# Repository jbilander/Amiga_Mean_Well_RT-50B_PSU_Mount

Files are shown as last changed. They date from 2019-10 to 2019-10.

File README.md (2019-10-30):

# Amiga Mean Well RT-50B PSU Mount
A 3d-printable PSU Mount for Mean Well RT-50B to fit inside an old Amiga PSU enclosure, two different versions

<a href="images/Amiga_Mean_Well_RT-50B_PSU.jpg">
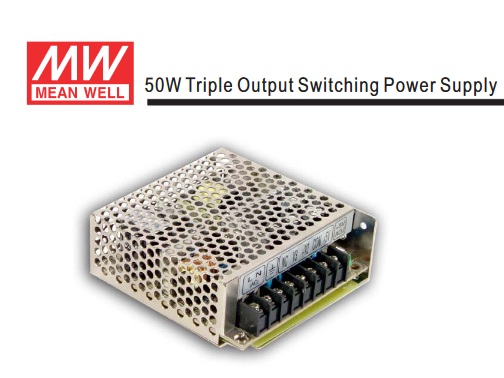
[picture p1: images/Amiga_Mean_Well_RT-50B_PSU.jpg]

</a>
<a href="images/V1/Amiga_Mean_Well_RT-50B_PSU_Mount_V1_pic1.jpg">
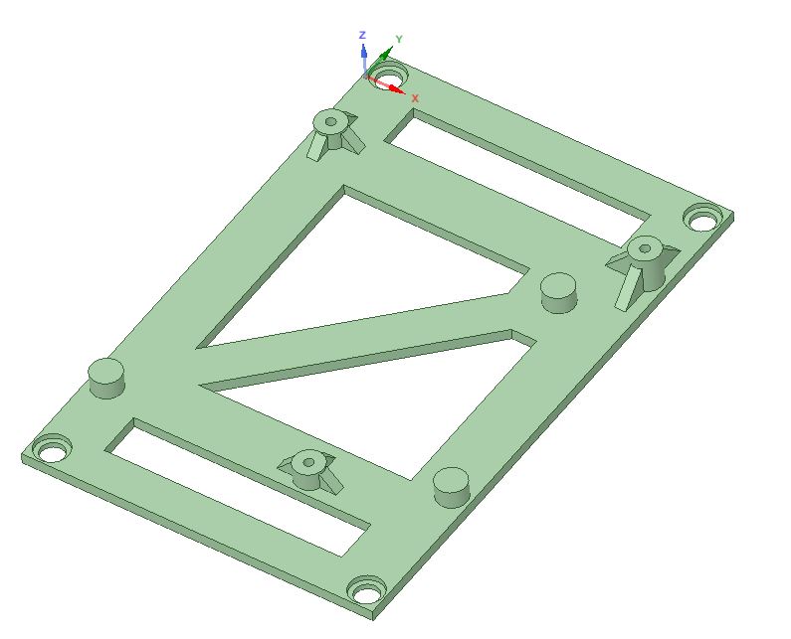
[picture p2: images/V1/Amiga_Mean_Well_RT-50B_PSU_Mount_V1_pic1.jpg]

</a>
<a href="images/V2/Amiga_Mean_Well_RT-50B_PSU_Mount_V2_pic1.jpg">
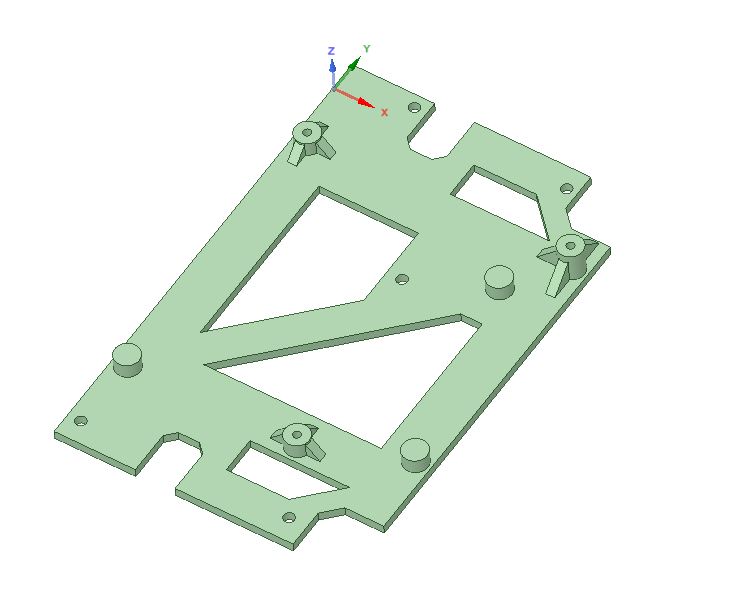
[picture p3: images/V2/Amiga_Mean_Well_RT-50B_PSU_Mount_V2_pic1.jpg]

</a>

The 3d-models was created in DesignSpark Mechanical 4.0

These two brackets fit different versions of the A500 PSU Enclosure

### Version 1

I did this 3d-print in ABS filament 250°/120° (Nozzle/Bed). It took ~4 hours. As you can see it is a snug fit in this old type of PSU case. I had to sand off a little of the ventilation fins on the sides in order for the Mean Well to fit in the case.

<a href="images/V1/Amiga_Mean_Well_RT-50B_PSU_Mount_V1_pic2.jpg">
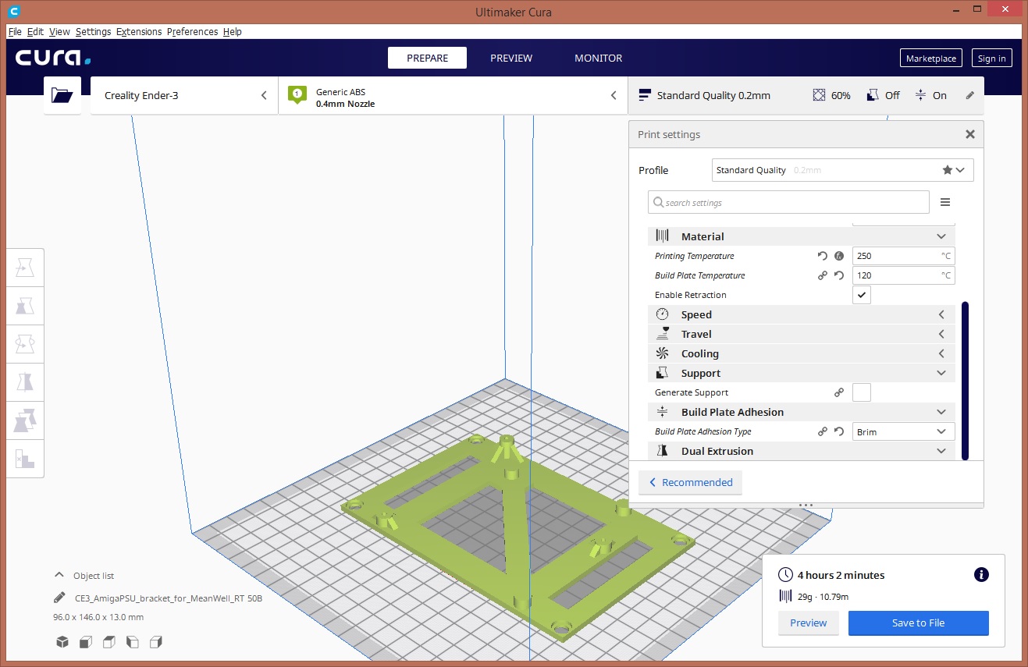
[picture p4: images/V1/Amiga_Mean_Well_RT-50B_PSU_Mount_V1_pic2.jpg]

</a>
<a href="images/V1/Amiga_Mean_Well_RT-50B_PSU_Mount_V1_pic3.jpg">
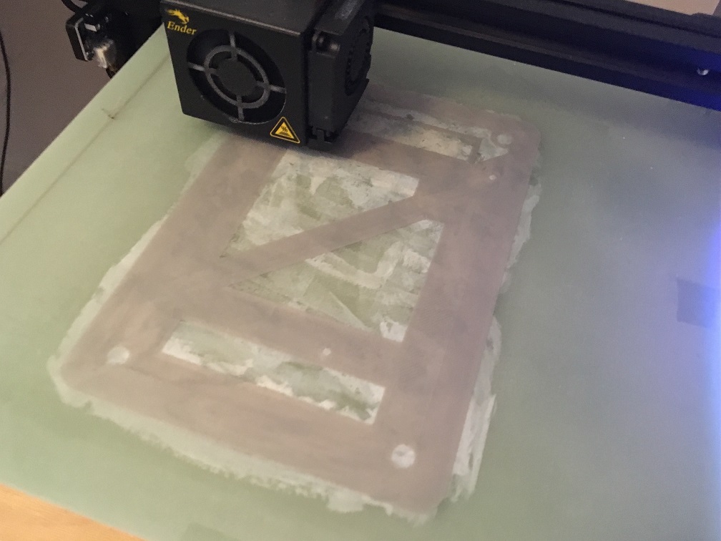
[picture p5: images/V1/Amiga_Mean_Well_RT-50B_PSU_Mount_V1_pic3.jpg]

</a>
<a href="images/V1/Amiga_Mean_Well_RT-50B_PSU_Mount_V1_pic4.jpg">
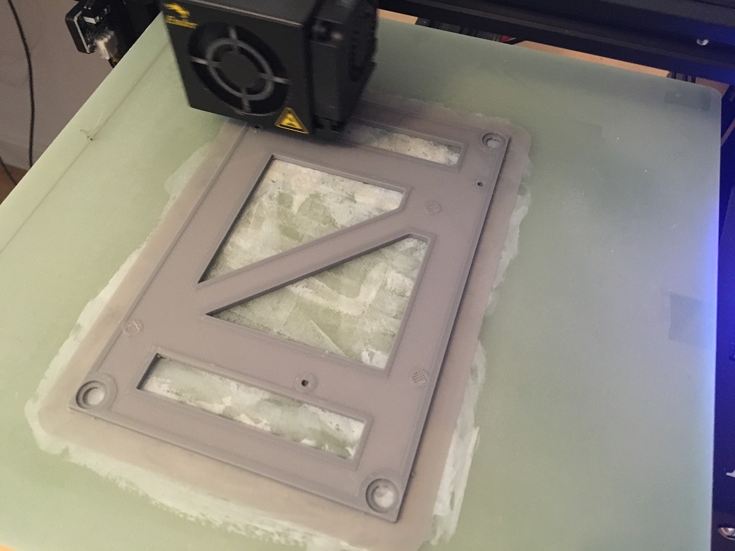
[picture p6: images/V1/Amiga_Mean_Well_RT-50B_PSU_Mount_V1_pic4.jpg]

</a>
<a href="images/V1/Amiga_Mean_Well_RT-50B_PSU_Mount_V1_pic5.jpg">
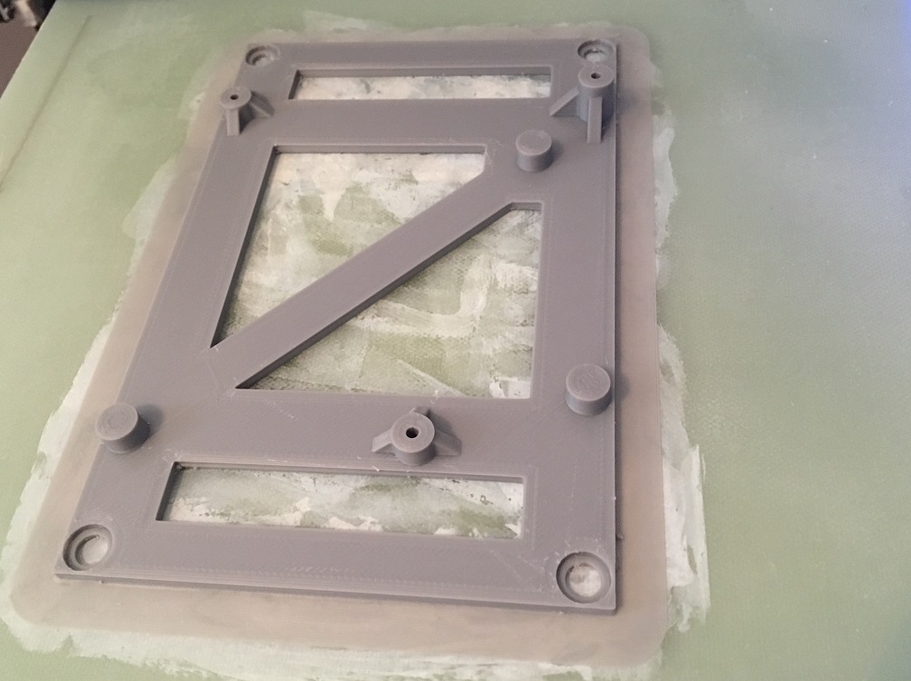
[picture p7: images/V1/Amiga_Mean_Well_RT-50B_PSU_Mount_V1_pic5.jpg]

</a>
<a href="images/V1/Amiga_Mean_Well_RT-50B_PSU_Mount_V1_pic6.jpg">
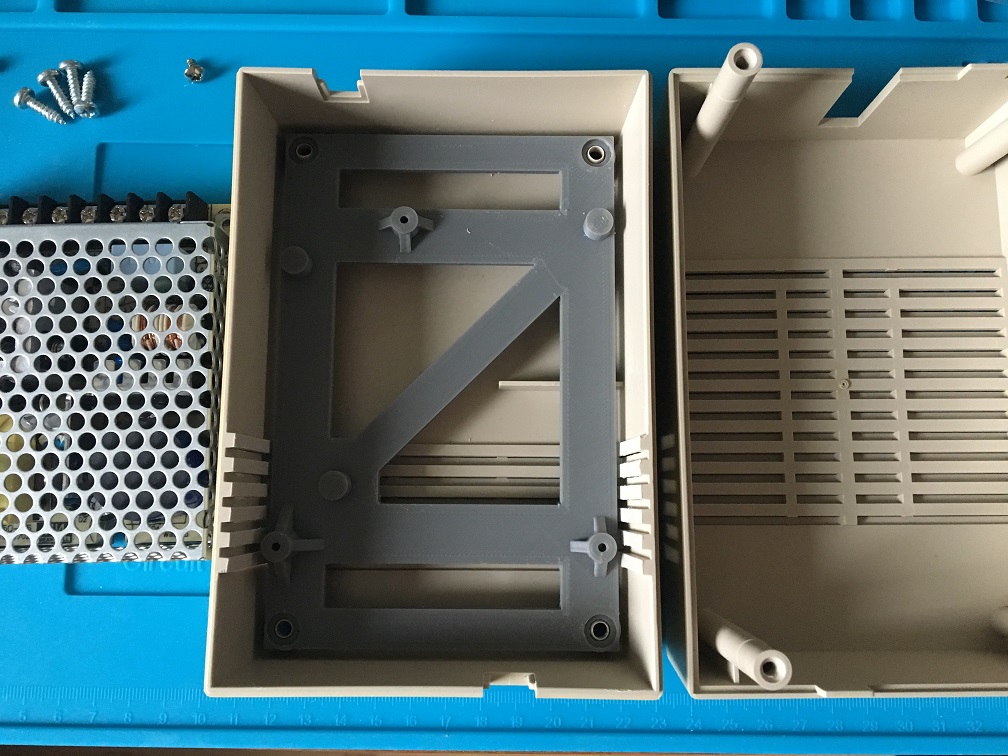
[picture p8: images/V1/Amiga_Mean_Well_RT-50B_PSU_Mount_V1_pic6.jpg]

</a>
<a href="images/V1/Amiga_Mean_Well_RT-50B_PSU_Mount_V1_pic7.jpg">
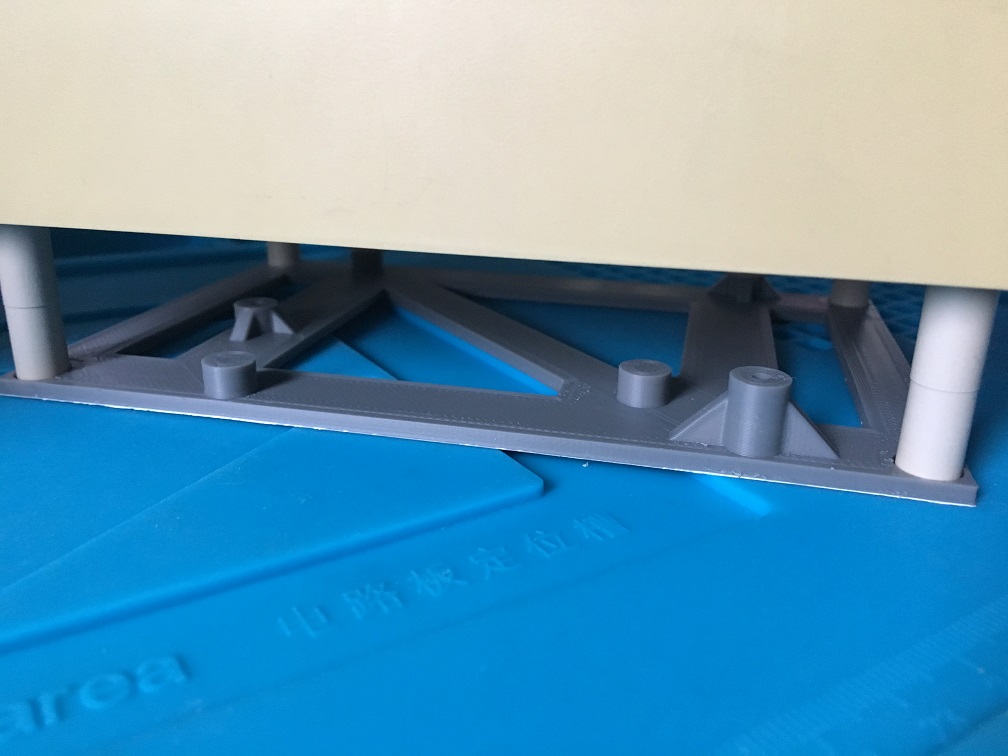
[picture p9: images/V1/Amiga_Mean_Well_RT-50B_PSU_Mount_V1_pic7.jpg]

</a>

***

I printed a standoff as well and glued it on to support the bracket. The standoff is of the same height 9,5 mm as the other psu standoffs. I took the screw from the Mean Well and reused it.

<a href="images/V1/Amiga_Mean_Well_RT-50B_PSU_Mount_V1_pic8.jpg">
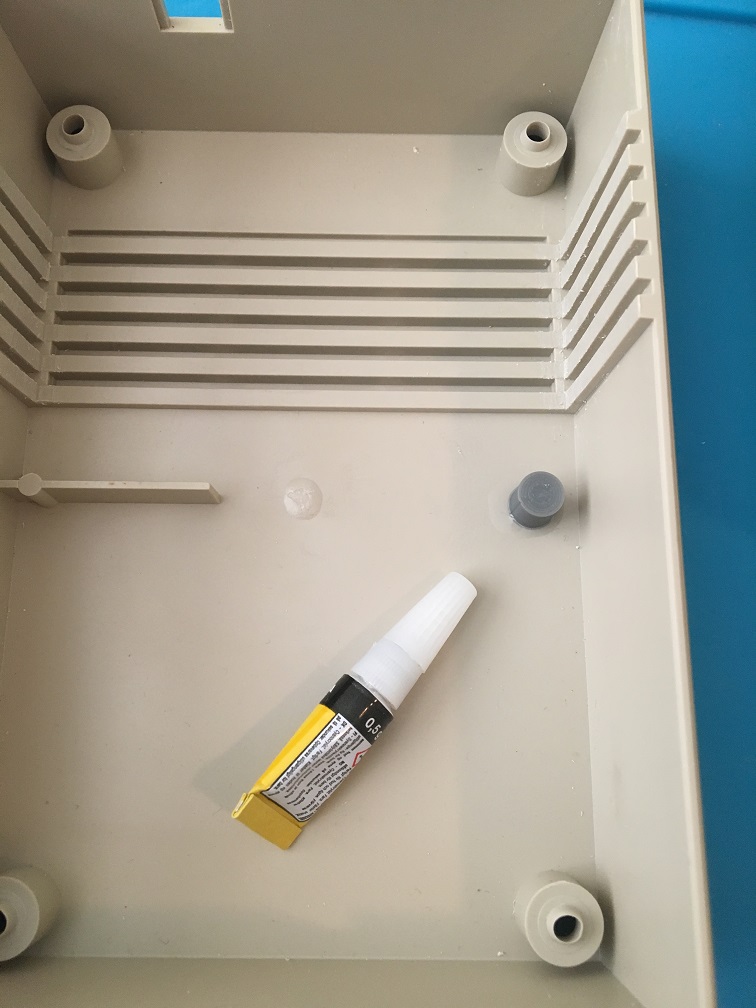
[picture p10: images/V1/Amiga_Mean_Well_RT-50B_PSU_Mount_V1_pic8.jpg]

</a>
<a href="images/V1/Amiga_Mean_Well_RT-50B_PSU_Mount_V1_pic9.jpg">
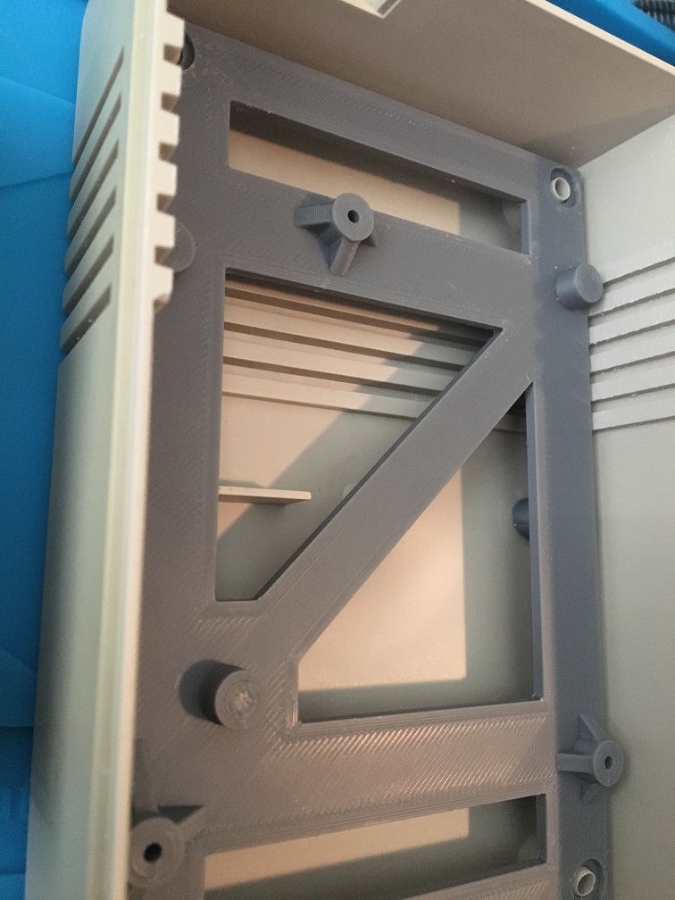
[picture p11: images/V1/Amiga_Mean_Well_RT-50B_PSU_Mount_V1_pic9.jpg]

</a>
<a href="images/V1/Amiga_Mean_Well_RT-50B_PSU_Mount_V1_pic10.jpg">
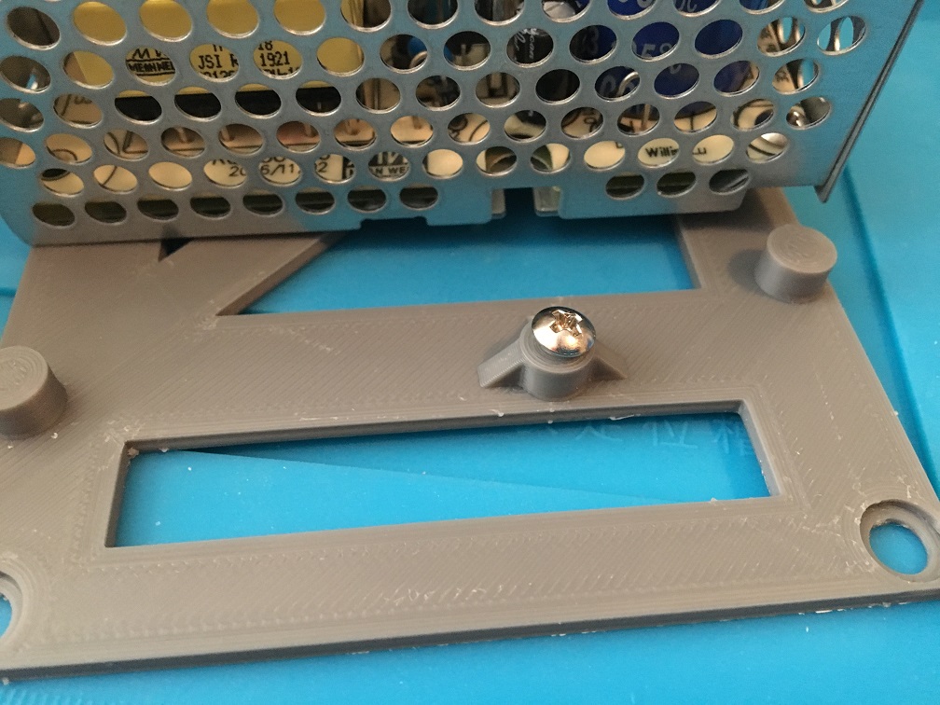
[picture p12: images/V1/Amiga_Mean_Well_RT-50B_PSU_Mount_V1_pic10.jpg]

</a>
<a href="images/V1/Amiga_Mean_Well_RT-50B_PSU_Mount_V1_pic11.jpg">
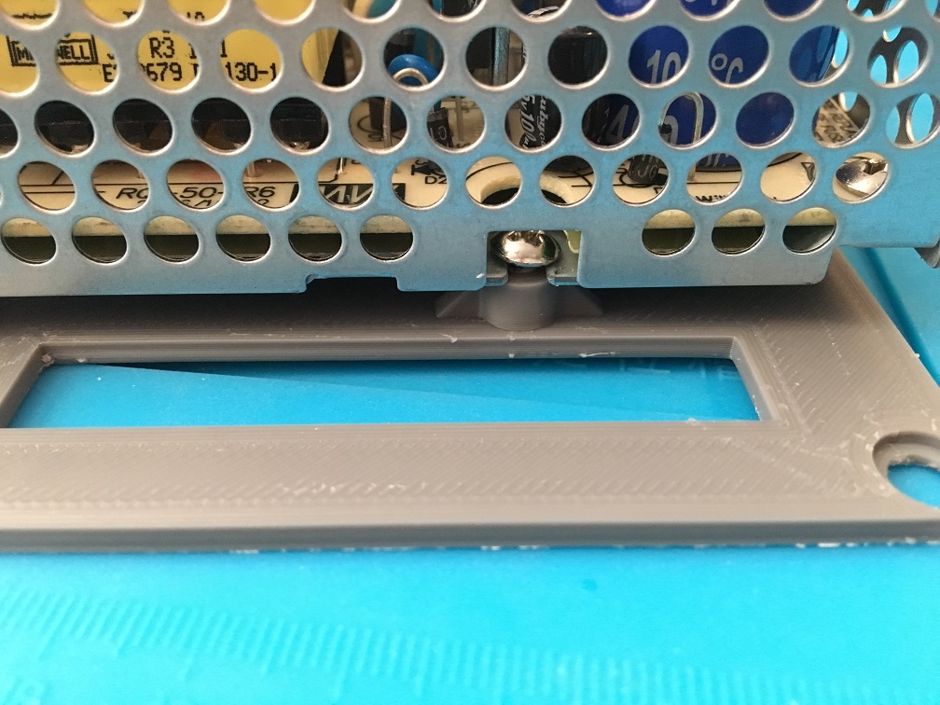
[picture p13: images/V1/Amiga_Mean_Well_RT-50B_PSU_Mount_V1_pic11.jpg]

</a>
<a href="images/V1/Amiga_Mean_Well_RT-50B_PSU_Mount_V1_pic12.jpg">
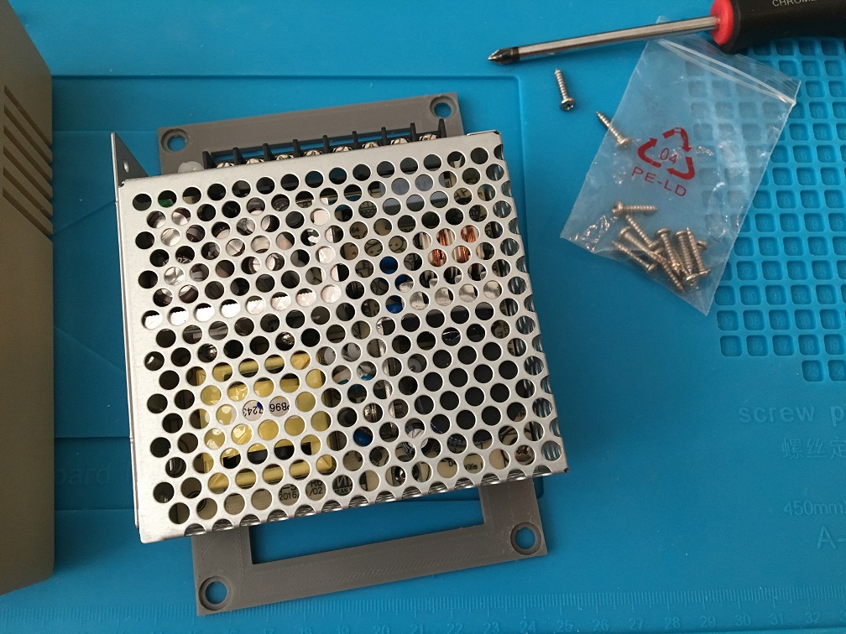
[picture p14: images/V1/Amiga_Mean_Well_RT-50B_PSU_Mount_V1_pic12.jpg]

</a>
<a href="images/V1/Amiga_Mean_Well_RT-50B_PSU_Mount_V1_pic13.jpg">
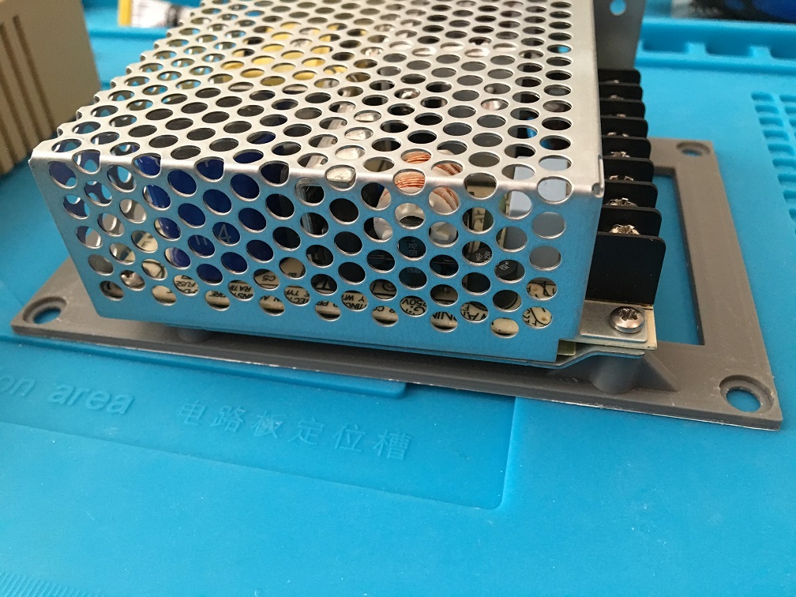
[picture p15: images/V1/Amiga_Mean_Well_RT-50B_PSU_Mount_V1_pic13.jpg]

</a>
<a href="images/V1/Amiga_Mean_Well_RT-50B_PSU_Mount_V1_pic14.jpg">
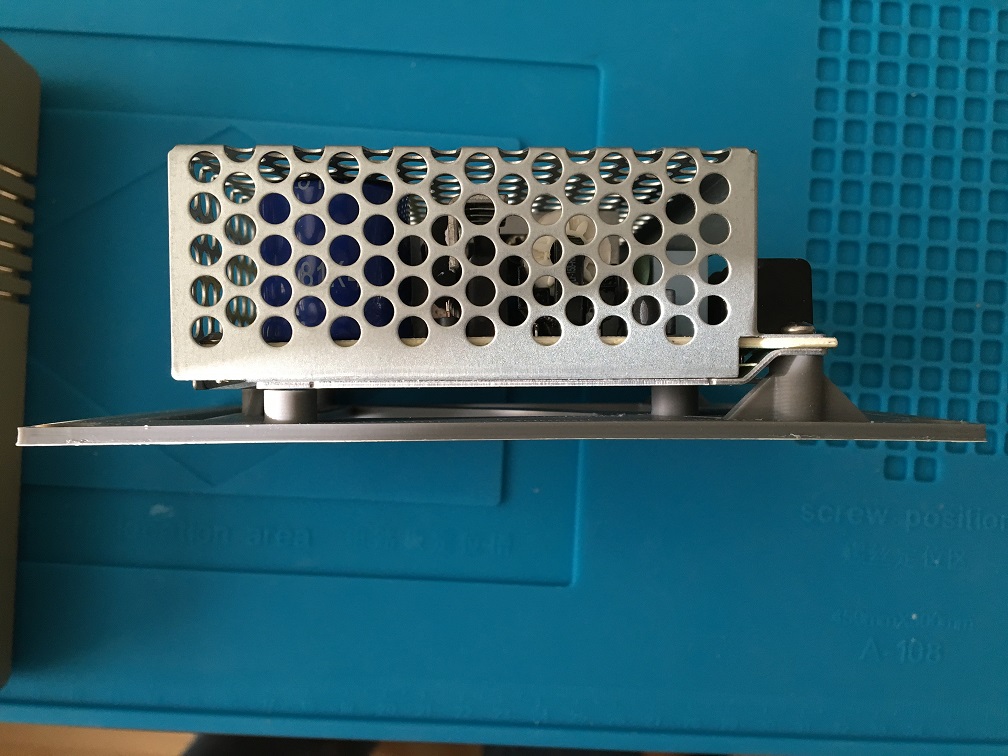
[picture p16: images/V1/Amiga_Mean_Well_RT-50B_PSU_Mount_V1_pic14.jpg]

</a>
<a href="images/V1/Amiga_Mean_Well_RT-50B_PSU_Mount_V1_pic15.jpg">
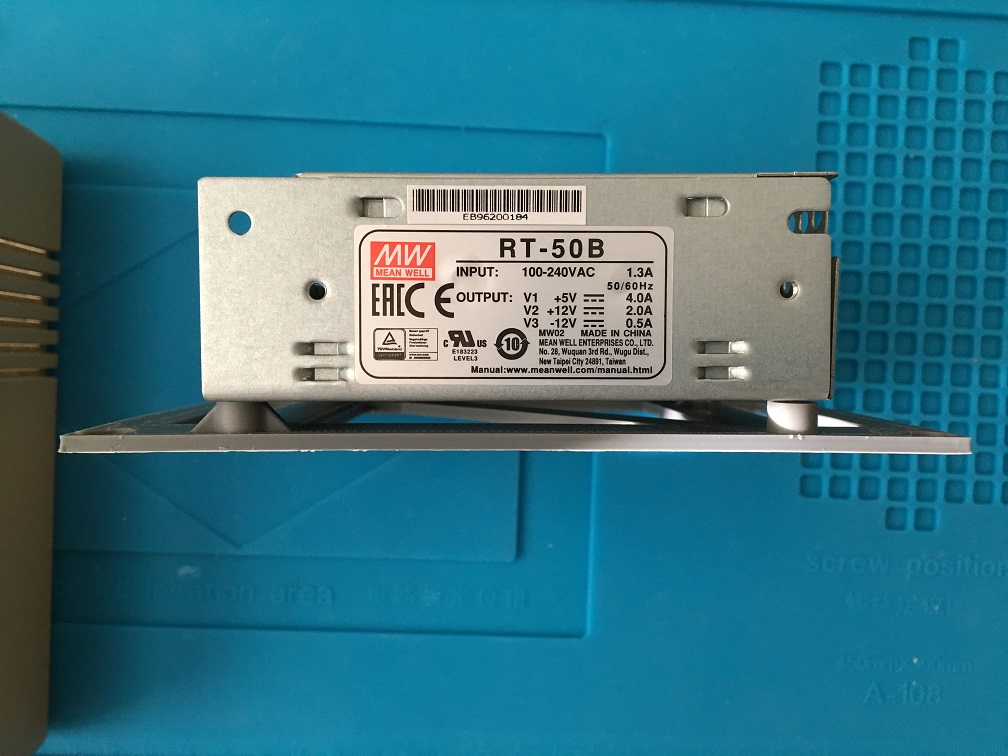
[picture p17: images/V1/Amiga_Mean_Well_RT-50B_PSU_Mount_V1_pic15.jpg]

</a>
<a href="images/V1/Amiga_Mean_Well_RT-50B_PSU_Mount_V1_pic16.jpg">
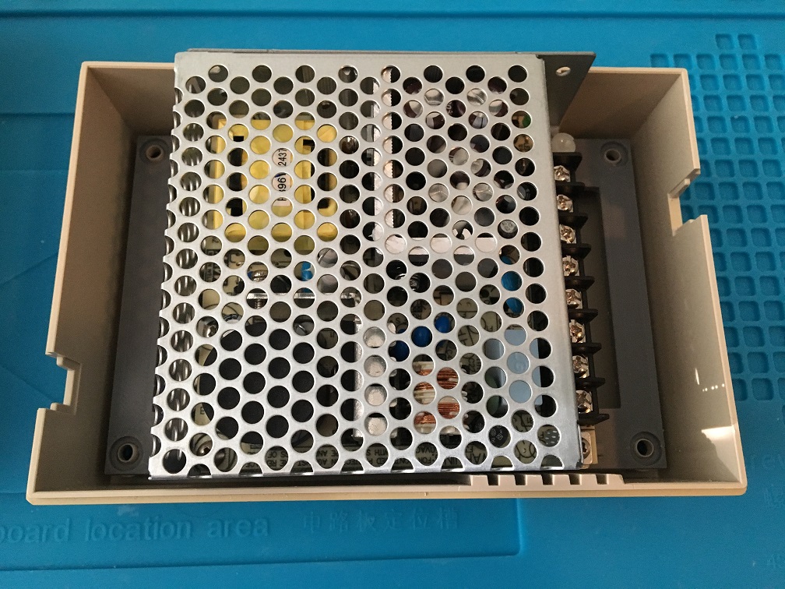
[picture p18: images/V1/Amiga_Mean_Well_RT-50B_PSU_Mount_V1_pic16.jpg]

</a>
<a href="images/V1/Amiga_Mean_Well_RT-50B_PSU_Mount_V1_pic17.jpg">
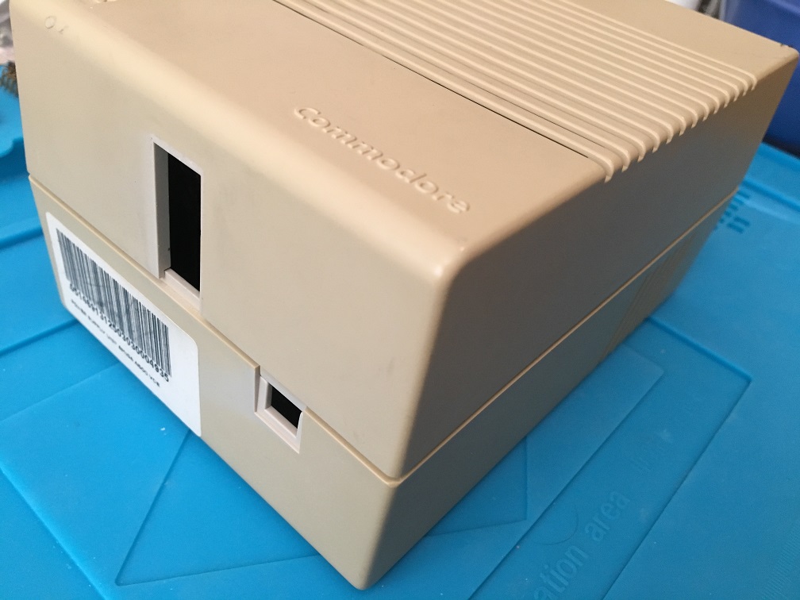
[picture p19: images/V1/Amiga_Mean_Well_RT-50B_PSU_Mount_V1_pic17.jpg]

</a>

***

Wiring it up...

Attention: Read the <a href="LEGAL_DISCLAIMER.md">Legal Disclaimer</a> before doing any electrical work yourself.

    Yellow = GND/Shield/Earth (double check this is indeed shield, in some cables yellow is in connection with red +5V and shield is other wire)
    White = -12V
    Brown = +12V
    Red = +5V
    Black = 0V/Signal GND

<a href="images/Amiga_PSU_pinout_pic1.jpg">
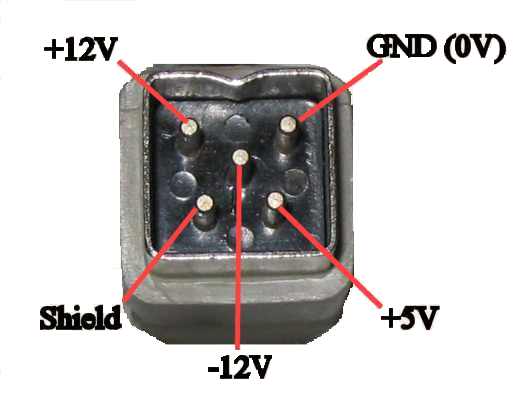
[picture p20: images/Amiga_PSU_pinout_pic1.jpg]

</a>
<a href="images/Amiga_PSU_pinout_pic2.JPG">
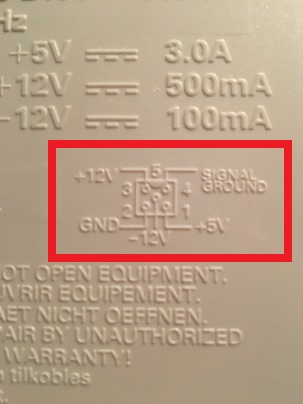
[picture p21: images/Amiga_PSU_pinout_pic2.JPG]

</a>

I used some power resistors to get a dummy load on. Check <a href="https://github.com/jbilander/AmigaPSU_Enclosure_for_Mean_Well_RT-50B">here</a> for reason behind this.

<a href="images/V1/Amiga_Mean_Well_RT-50B_PSU_Mount_V1_pic18.jpg">
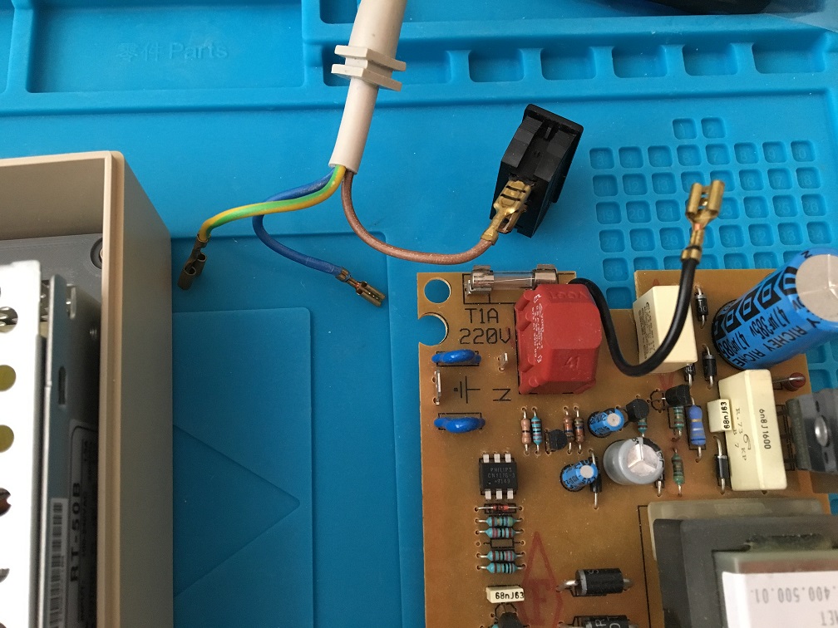
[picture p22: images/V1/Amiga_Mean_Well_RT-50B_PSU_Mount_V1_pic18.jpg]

</a>
<a href="images/V1/Amiga_Mean_Well_RT-50B_PSU_Mount_V1_pic19.jpg">
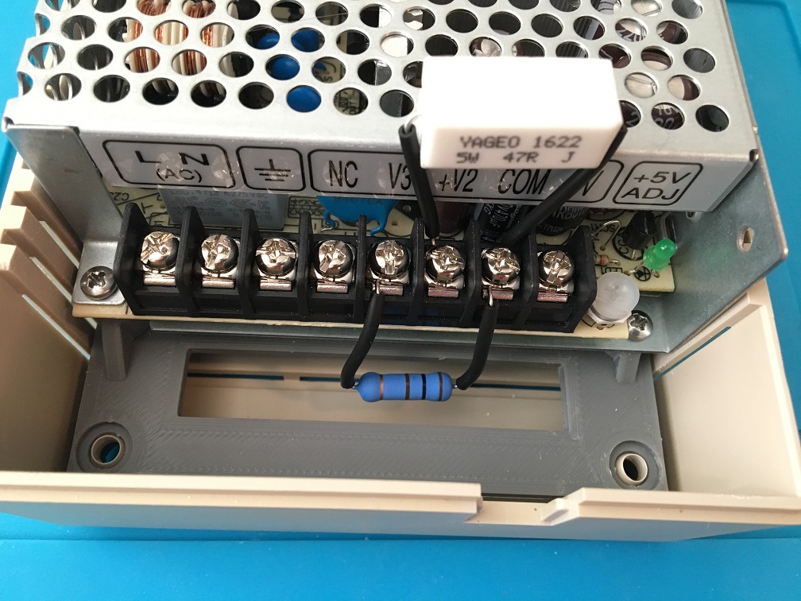
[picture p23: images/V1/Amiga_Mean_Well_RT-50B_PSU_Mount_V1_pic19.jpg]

</a>
<a href="images/V1/Amiga_Mean_Well_RT-50B_PSU_Mount_V1_pic20.jpg">
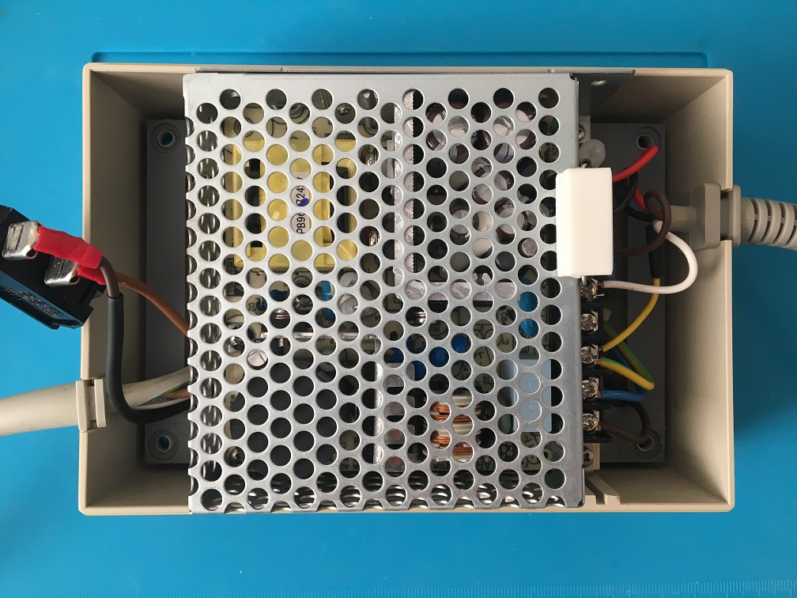
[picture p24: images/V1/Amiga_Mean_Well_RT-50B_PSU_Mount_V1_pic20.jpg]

</a>
<a href="images/V1/Amiga_Mean_Well_RT-50B_PSU_Mount_V1_pic21.jpg">
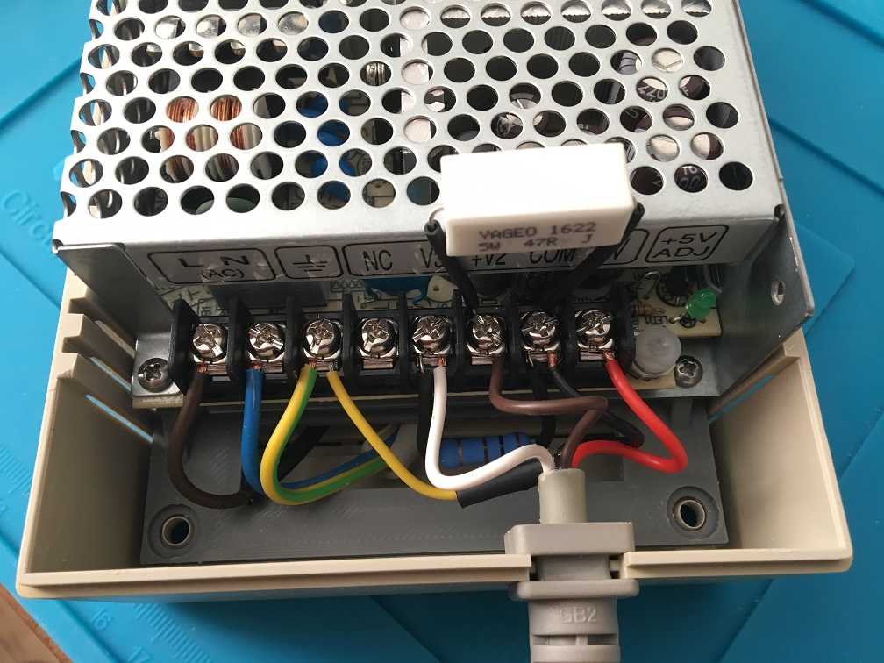
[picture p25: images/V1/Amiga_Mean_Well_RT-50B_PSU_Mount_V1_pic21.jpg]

</a>

***

Checking potentials and verifying cable...

<a href="images/V1/Amiga_Mean_Well_RT-50B_PSU_Mount_V1_pic22.jpg">
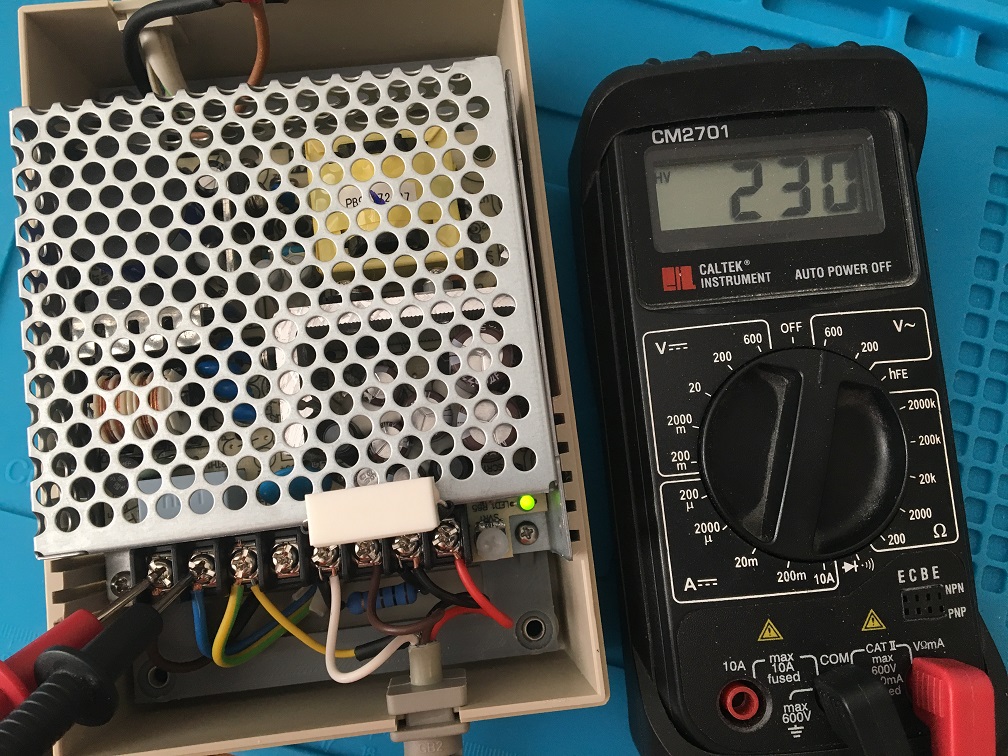
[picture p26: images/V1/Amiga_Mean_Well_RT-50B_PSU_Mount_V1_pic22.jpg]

</a>
<a href="images/V1/Amiga_Mean_Well_RT-50B_PSU_Mount_V1_pic23.jpg">
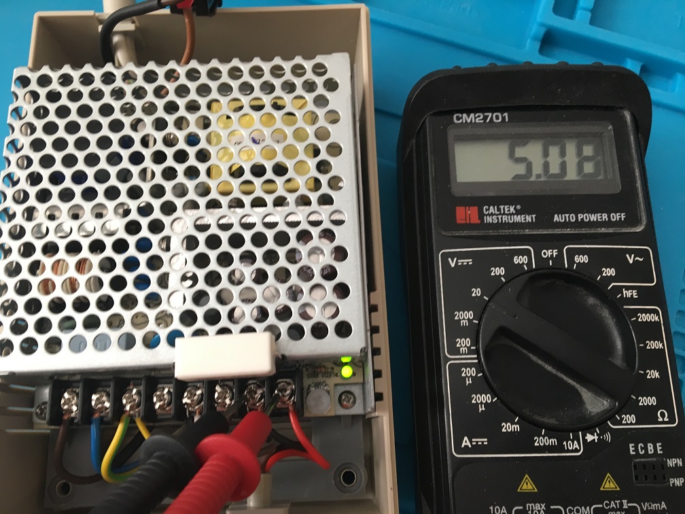
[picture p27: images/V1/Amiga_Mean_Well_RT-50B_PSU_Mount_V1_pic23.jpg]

</a>
<a href="images/V1/Amiga_Mean_Well_RT-50B_PSU_Mount_V1_pic24.jpg">
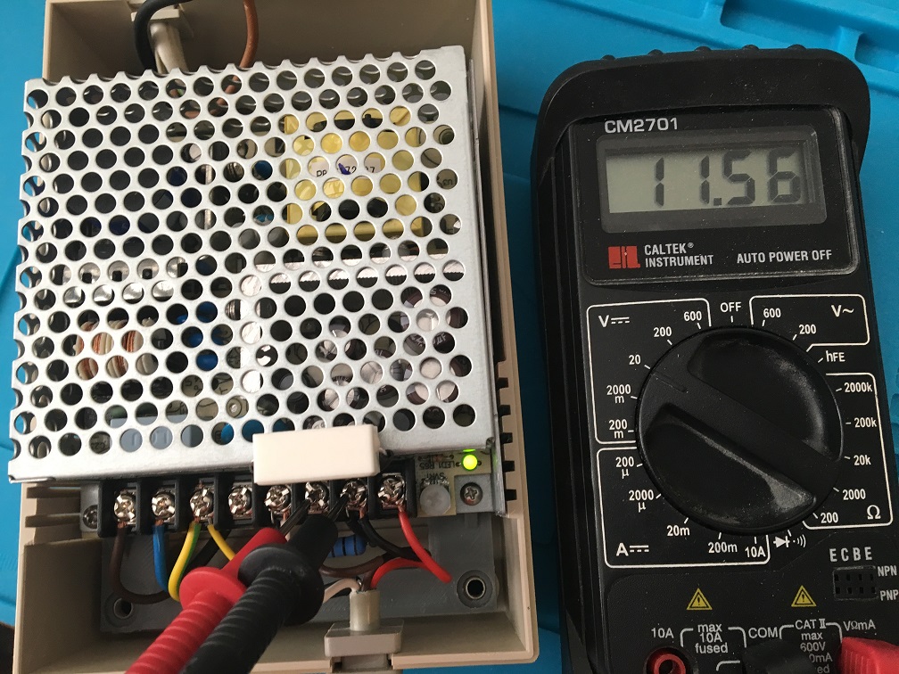
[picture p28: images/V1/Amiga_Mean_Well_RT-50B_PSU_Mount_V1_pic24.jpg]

</a>
<a href="images/V1/Amiga_Mean_Well_RT-50B_PSU_Mount_V1_pic25.jpg">
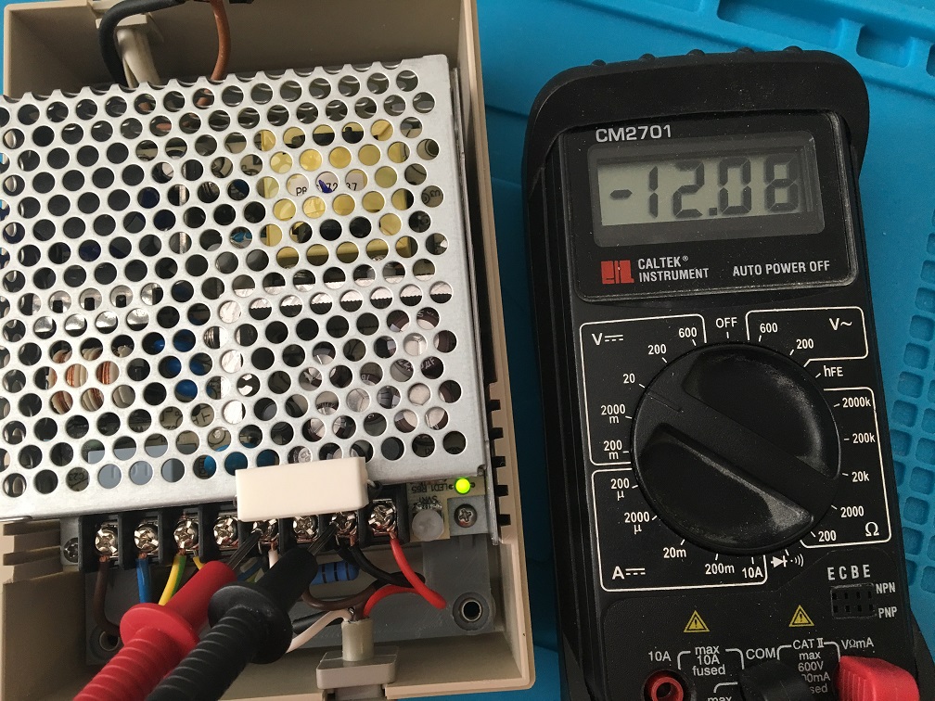
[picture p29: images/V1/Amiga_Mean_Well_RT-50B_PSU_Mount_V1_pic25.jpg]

</a>
<a href="images/V1/Amiga_Mean_Well_RT-50B_PSU_Mount_V1_pic29.jpg">
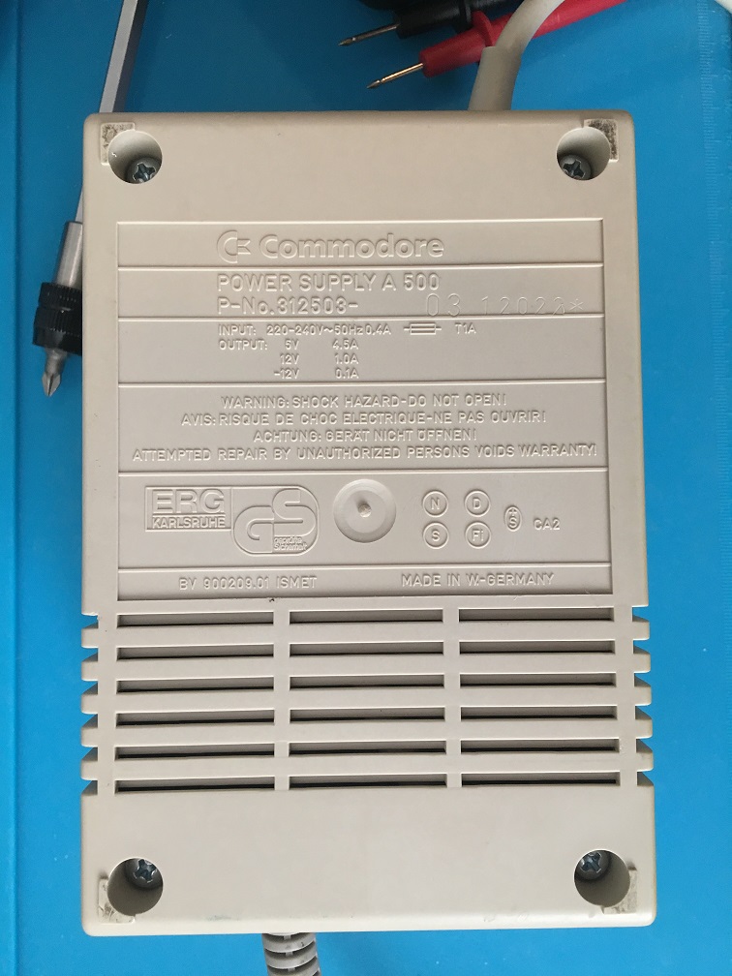
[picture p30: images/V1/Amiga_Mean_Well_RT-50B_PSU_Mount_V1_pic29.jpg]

</a>
<a href="images/V1/Amiga_Mean_Well_RT-50B_PSU_Mount_V1_pic30.jpg">
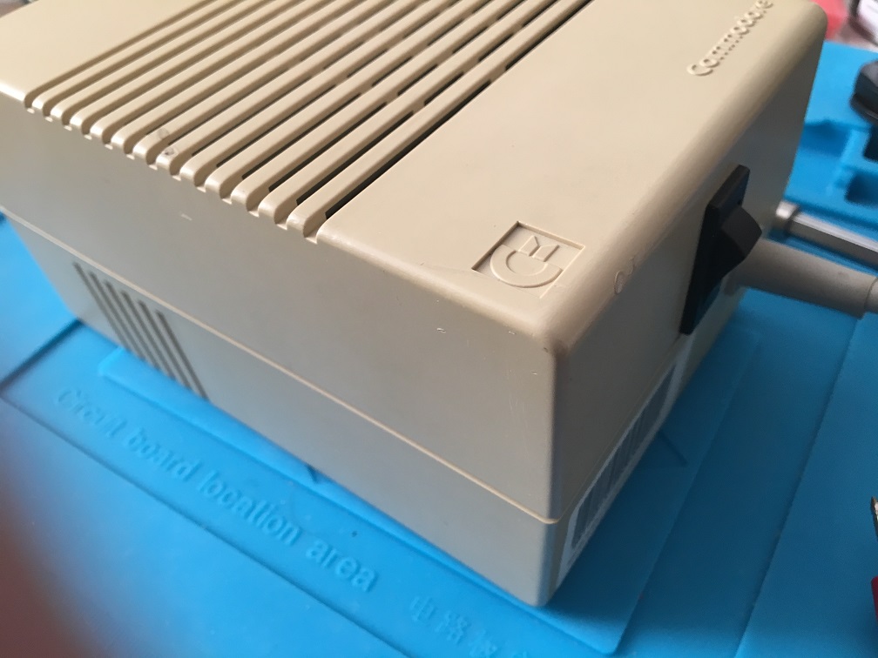
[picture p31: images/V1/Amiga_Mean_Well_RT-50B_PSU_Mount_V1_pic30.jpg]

</a>
<a href="images/V1/Amiga_Mean_Well_RT-50B_PSU_Mount_V1_pic26.jpg">
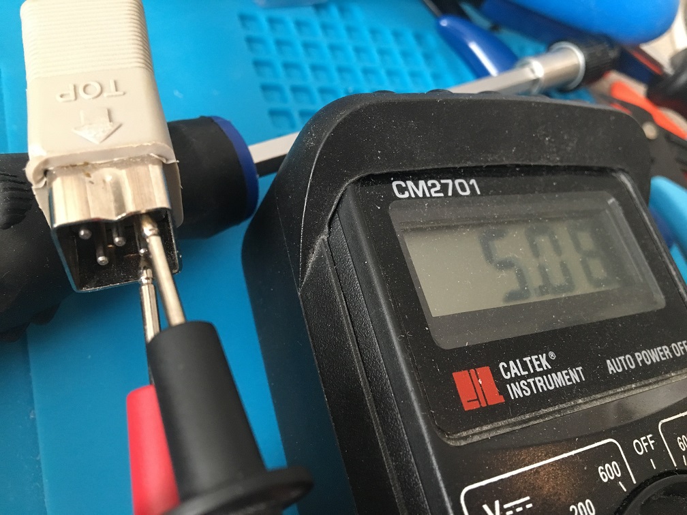
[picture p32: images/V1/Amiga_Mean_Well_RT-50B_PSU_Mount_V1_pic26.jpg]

</a>
<a href="images/V1/Amiga_Mean_Well_RT-50B_PSU_Mount_V1_pic27.jpg">
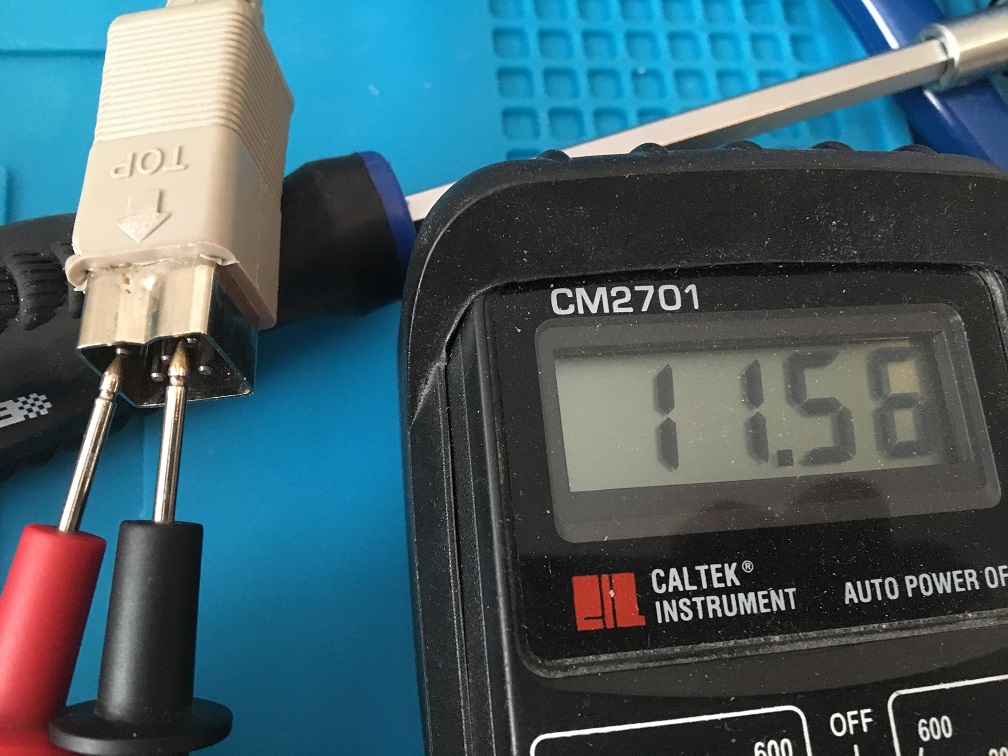
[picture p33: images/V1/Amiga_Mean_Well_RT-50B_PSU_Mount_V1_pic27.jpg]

</a>
<a href="images/V1/Amiga_Mean_Well_RT-50B_PSU_Mount_V1_pic28.jpg">
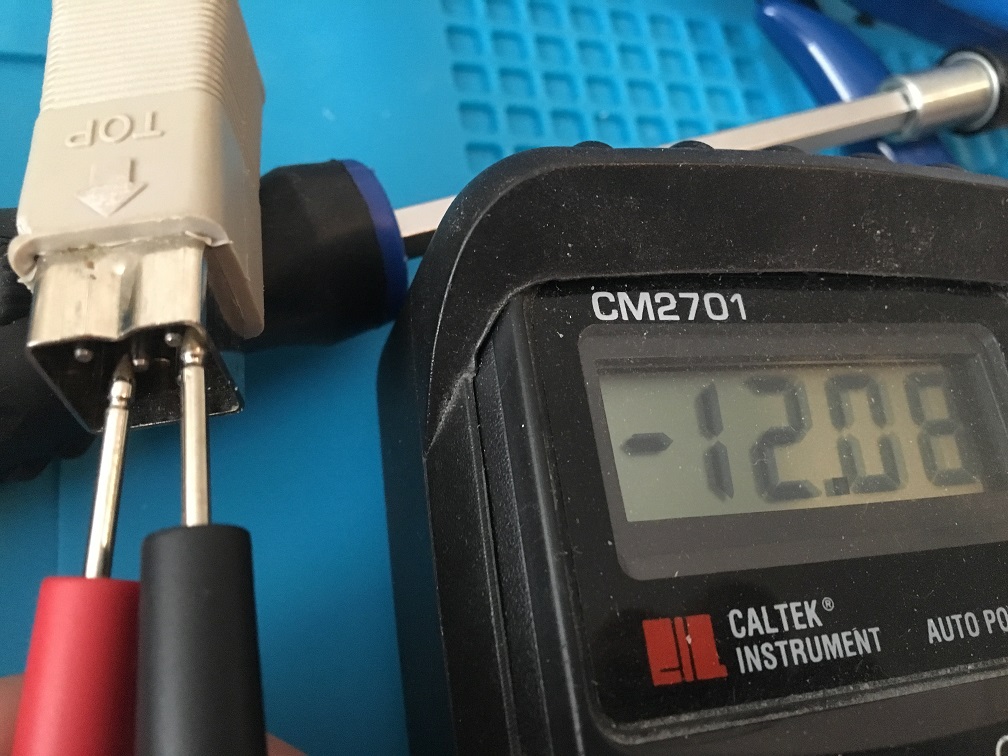
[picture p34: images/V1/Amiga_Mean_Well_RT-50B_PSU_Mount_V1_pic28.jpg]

</a>

All done version 1!!

***

### Version 2

I did this 3d-print in ABS filament 250°/120° (Nozzle/Bed). It took ~4 hours. As you can see it is a snug fit with this type of PSU case.

<a href="images/V2/Amiga_Mean_Well_RT-50B_PSU_Mount_V2_pic2.jpg">
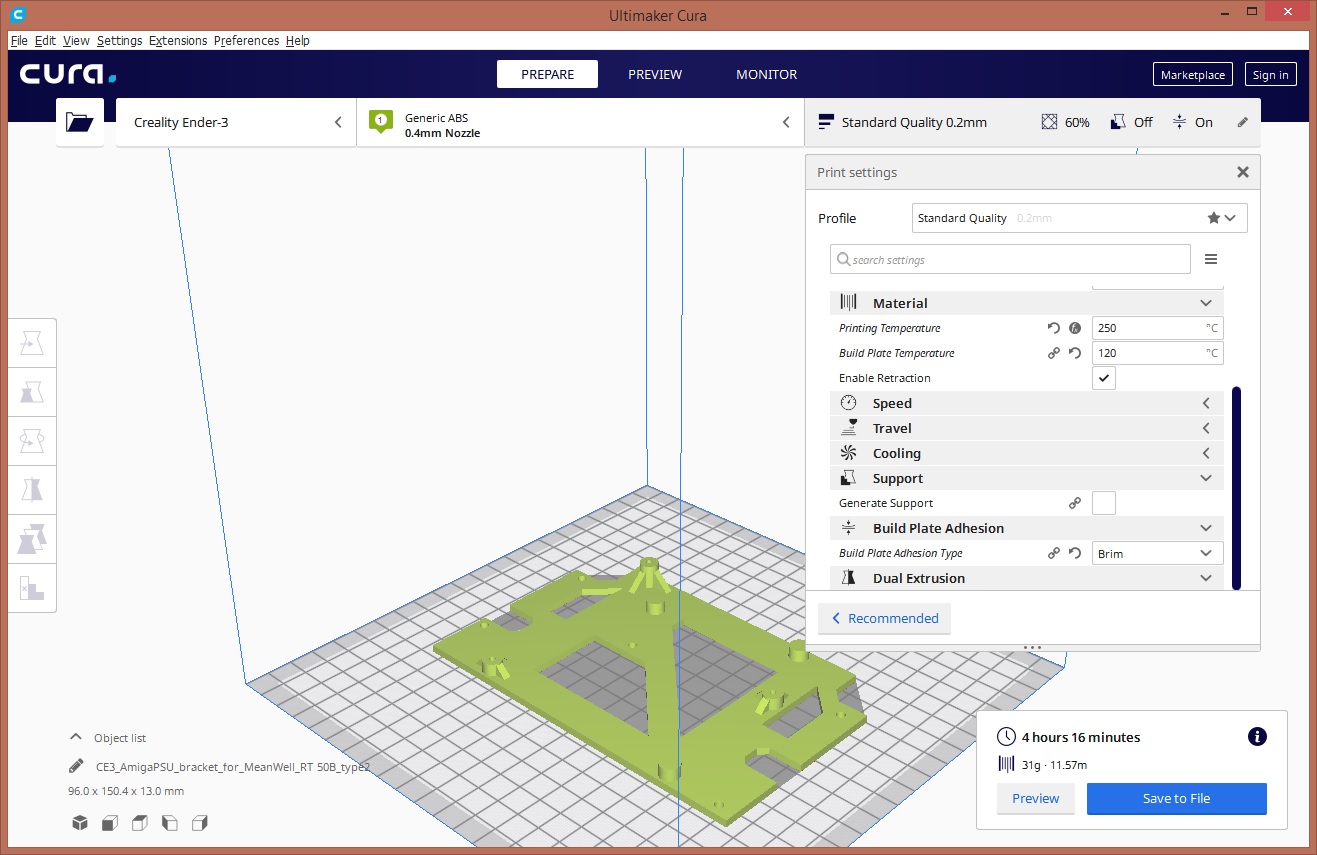
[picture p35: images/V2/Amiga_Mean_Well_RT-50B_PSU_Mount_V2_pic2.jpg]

</a>
<a href="images/V2/Amiga_Mean_Well_RT-50B_PSU_Mount_V2_pic3.jpg">
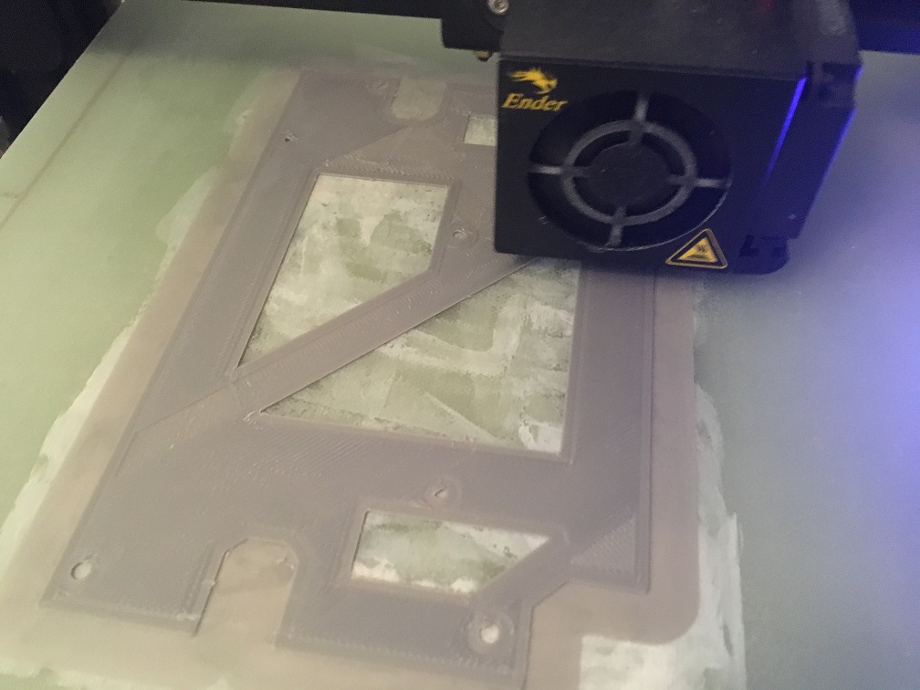
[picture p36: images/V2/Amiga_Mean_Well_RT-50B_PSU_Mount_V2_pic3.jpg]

</a>
<a href="images/V2/Amiga_Mean_Well_RT-50B_PSU_Mount_V2_pic4.jpg">
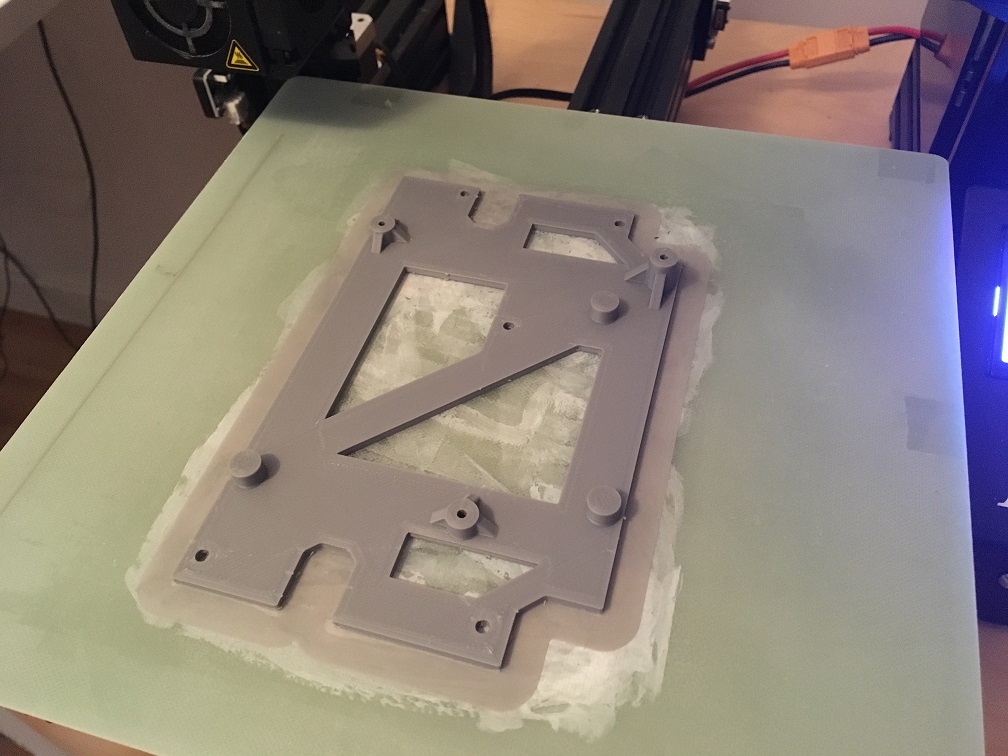
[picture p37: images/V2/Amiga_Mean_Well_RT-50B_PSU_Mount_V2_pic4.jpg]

</a>
<a href="images/V2/Amiga_Mean_Well_RT-50B_PSU_Mount_V2_pic5.jpg">
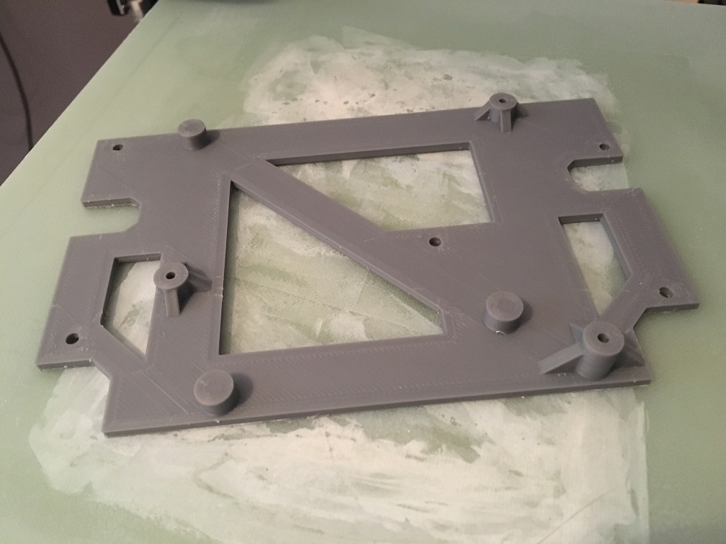
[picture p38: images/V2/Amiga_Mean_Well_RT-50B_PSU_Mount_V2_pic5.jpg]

</a>
<a href="images/V2/Amiga_Mean_Well_RT-50B_PSU_Mount_V2_pic6.jpg">
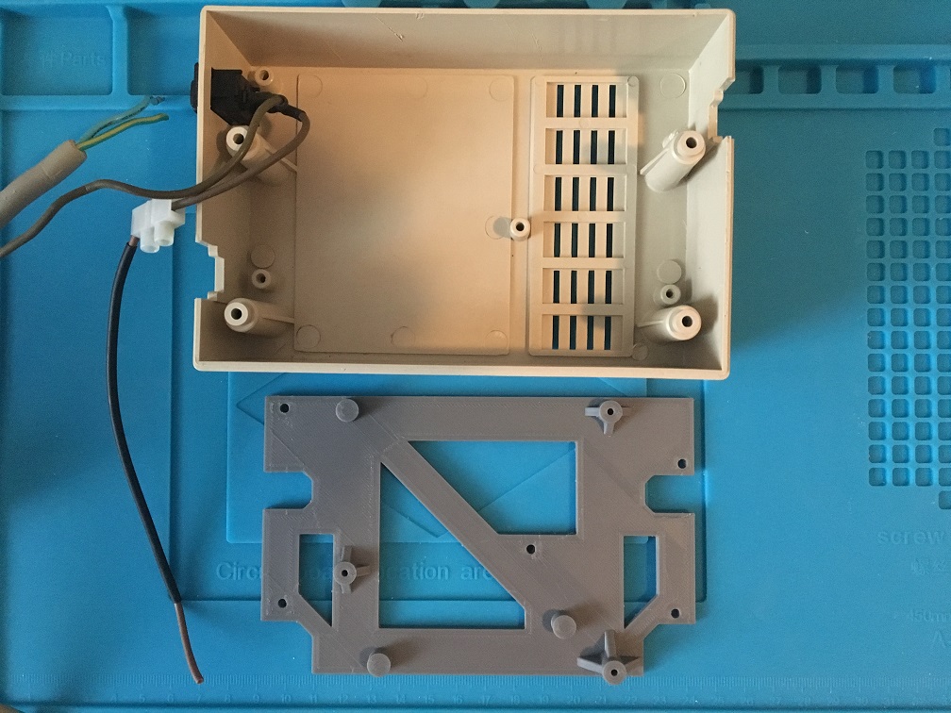
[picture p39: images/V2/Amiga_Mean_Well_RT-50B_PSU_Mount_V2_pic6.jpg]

</a>
<a href="images/V2/Amiga_Mean_Well_RT-50B_PSU_Mount_V2_pic7.jpg">
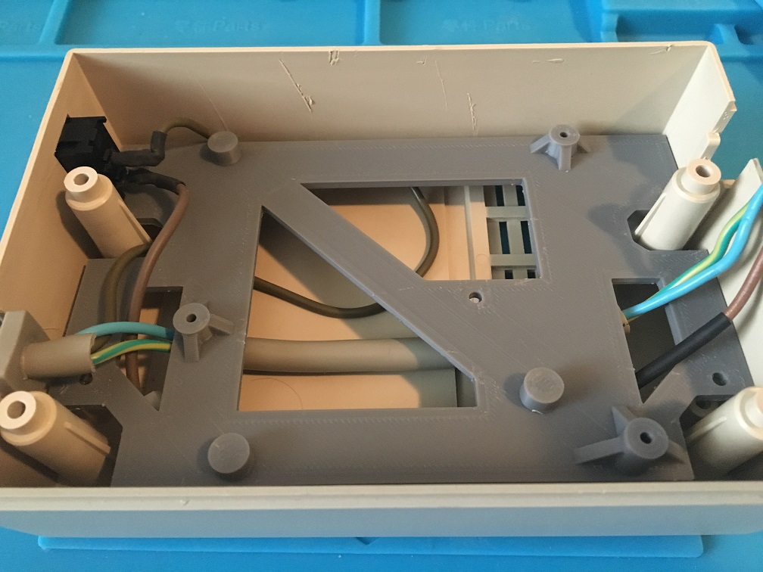
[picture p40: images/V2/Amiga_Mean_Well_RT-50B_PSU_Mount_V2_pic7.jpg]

</a>

***

I took the screw from the Mean Well and reused it.

<a href="images/V2/Amiga_Mean_Well_RT-50B_PSU_Mount_V2_pic8.jpg">

</a>
<a href="images/V2/Amiga_Mean_Well_RT-50B_PSU_Mount_V2_pic9.jpg">

</a>
<a href="images/V2/Amiga_Mean_Well_RT-50B_PSU_Mount_V2_pic10.jpg">

</a>

***

Wiring it up...

Attention: Read the <a href="LEGAL_DISCLAIMER.md">Legal Disclaimer</a> before doing any electrical work yourself.

    Brown = Line 230V
    Blue = Neutral
    Green/Yellow = GND

<a href="images/V2/Amiga_Mean_Well_RT-50B_PSU_Mount_V2_pic11.jpg">

</a>

<br />

<a href="images/Amiga_PSU_pinout_pic1.jpg">

</a>
<a href="images/Amiga_PSU_pinout_pic2.JPG">

</a>

    Thick Black = GND/Shield/Earth (NOT yellow here as that one was connected with red +5V in this cable)
    White = -12V
    Brown = +12V
    Red = +5V
    Yellow = +5V (not needed/used here)
    Black = 0V/Signal GND

<a href="images/V2/Amiga_Mean_Well_RT-50B_PSU_Mount_V2_pic12.jpg">

</a>
<a href="images/V2/Amiga_Mean_Well_RT-50B_PSU_Mount_V2_pic13.jpg">

</a>

I used some power resistors to get a dummy load on. Check <a href="https://github.com/jbilander/AmigaPSU_Enclosure_for_Mean_Well_RT-50B">here</a> for reason behind this.

<a href="images/V2/Amiga_Mean_Well_RT-50B_PSU_Mount_V2_pic14.jpg">

</a>
<a href="images/V2/Amiga_Mean_Well_RT-50B_PSU_Mount_V2_pic15.jpg">

</a>
<a href="images/V2/Amiga_Mean_Well_RT-50B_PSU_Mount_V2_pic16.jpg">

</a>

Checking potentials and verifying cable...

<a href="images/V2/Amiga_Mean_Well_RT-50B_PSU_Mount_V2_pic17.jpg">

</a>
<a href="images/V2/Amiga_Mean_Well_RT-50B_PSU_Mount_V2_pic18.jpg">

</a>
<a href="images/V2/Amiga_Mean_Well_RT-50B_PSU_Mount_V2_pic19.jpg">

</a>
<a href="images/V2/Amiga_Mean_Well_RT-50B_PSU_Mount_V2_pic20.jpg">

</a>
<a href="images/V2/Amiga_Mean_Well_RT-50B_PSU_Mount_V2_pic21.jpg">

</a>
<a href="images/V2/Amiga_Mean_Well_RT-50B_PSU_Mount_V2_pic22.jpg">

</a>
<a href="images/V2/Amiga_Mean_Well_RT-50B_PSU_Mount_V2_pic23.jpg">

</a>
<a href="images/V2/Amiga_Mean_Well_RT-50B_PSU_Mount_V2_pic24.jpg">

</a>
<a href="images/V2/Amiga_Mean_Well_RT-50B_PSU_Mount_V2_pic25.jpg">

</a>

All done!

***

Now with another similar PSU Enclosure...

<a href="images/V2/Amiga_Mean_Well_RT-50B_PSU_Mount_V2_pic26.jpg">

</a>

I went medieval with a cutter on the annoying plastic, marked red below, to accomodate the bracket...

<a href="images/V2/Amiga_Mean_Well_RT-50B_PSU_Mount_V2_pic27.jpg">

</a>
<a href="images/V2/Amiga_Mean_Well_RT-50B_PSU_Mount_V2_pic28.jpg">

</a>

***

Now this type of enclosure didn't have any standoffs so I made one and printed it five times...The standoff is 6mm high which is enough of clearance for running wires under the bracket.

<a href="images/V2/Amiga_Mean_Well_RT-50B_PSU_Mount_V2_pic29.jpg">

</a>
<a href="images/V2/Amiga_Mean_Well_RT-50B_PSU_Mount_V2_pic30.jpg">

</a>

***

I glued the standoffs one-by-one using a screw and the bracket to get them in correct positions.

<a href="images/V2/Amiga_Mean_Well_RT-50B_PSU_Mount_V2_pic31.jpg">

</a>
<a href="images/V2/Amiga_Mean_Well_RT-50B_PSU_Mount_V2_pic32.jpg">

</a>
<a href="images/V2/Amiga_Mean_Well_RT-50B_PSU_Mount_V2_pic33.jpg">

</a>
<a href="images/V2/Amiga_Mean_Well_RT-50B_PSU_Mount_V2_pic34.jpg">

</a>

***

Made some more clearance for the power wires and mounted the Mean Well PSU.

<a href="images/V2/Amiga_Mean_Well_RT-50B_PSU_Mount_V2_pic35.jpg">

</a>
<a href="images/V2/Amiga_Mean_Well_RT-50B_PSU_Mount_V2_pic36.jpg">

</a>
<a href="images/V2/Amiga_Mean_Well_RT-50B_PSU_Mount_V2_pic37.jpg">

</a>
<a href="images/V2/Amiga_Mean_Well_RT-50B_PSU_Mount_V2_pic38.jpg">

</a>
<a href="images/V2/Amiga_Mean_Well_RT-50B_PSU_Mount_V2_pic39.jpg">

</a>
<a href="images/V2/Amiga_Mean_Well_RT-50B_PSU_Mount_V2_pic40.jpg">

</a>

***

I used some power resistors to get a dummy load on. Check <a href="https://github.com/jbilander/AmigaPSU_Enclosure_for_Mean_Well_RT-50B">here</a> for reason behind this. The dummy load energy dissipates as heat, hence the placement of the resistors touching the case that acts as a heat sink.

<a href="images/V2/Amiga_Mean_Well_RT-50B_PSU_Mount_V2_pic41.jpg">

</a>
<a href="images/V2/Amiga_Mean_Well_RT-50B_PSU_Mount_V2_pic42.jpg">

</a>
<a href="images/V2/Amiga_Mean_Well_RT-50B_PSU_Mount_V2_pic43.jpg">

</a>
<a href="images/V2/Amiga_Mean_Well_RT-50B_PSU_Mount_V2_pic44.jpg">

</a>
<a href="images/V2/Amiga_Mean_Well_RT-50B_PSU_Mount_V2_pic45.jpg">

</a>
<a href="images/V2/Amiga_Mean_Well_RT-50B_PSU_Mount_V2_pic46.jpg">

</a>

***

Checking potentials and verifying cable...

<a href="images/V2/Amiga_Mean_Well_RT-50B_PSU_Mount_V2_pic48.jpg">

</a>
<a href="images/V2/Amiga_Mean_Well_RT-50B_PSU_Mount_V2_pic49.jpg">

</a>
<a href="images/V2/Amiga_Mean_Well_RT-50B_PSU_Mount_V2_pic50.jpg">

</a>
<a href="images/V2/Amiga_Mean_Well_RT-50B_PSU_Mount_V2_pic51.jpg">

</a>
<a href="images/V2/Amiga_Mean_Well_RT-50B_PSU_Mount_V2_pic52.jpg">

</a>
<a href="images/V2/Amiga_Mean_Well_RT-50B_PSU_Mount_V2_pic53.jpg">

</a>
<a href="images/V2/Amiga_Mean_Well_RT-50B_PSU_Mount_V2_pic54.jpg">

</a>
<a href="images/V2/Amiga_Mean_Well_RT-50B_PSU_Mount_V2_pic55.jpg">

</a>

***

All done!

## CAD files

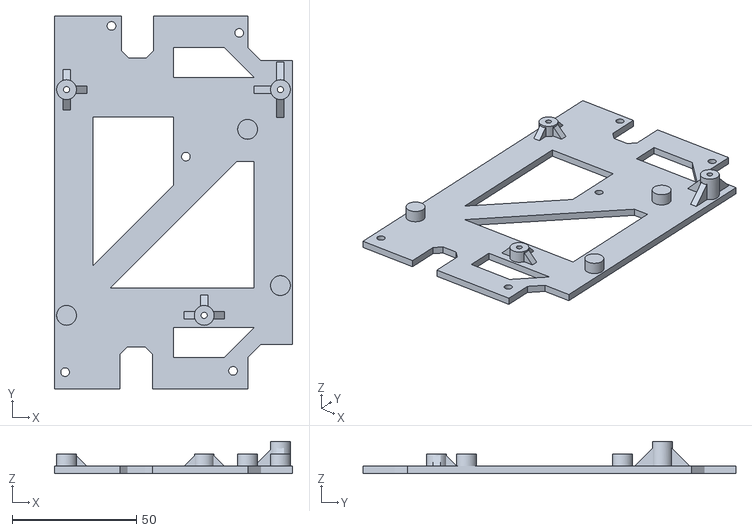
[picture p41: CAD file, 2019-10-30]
Amiga_Mean_Well_RT-50B_PSU_Mount_V2.stl
96.0 x 150.4 x 13.0

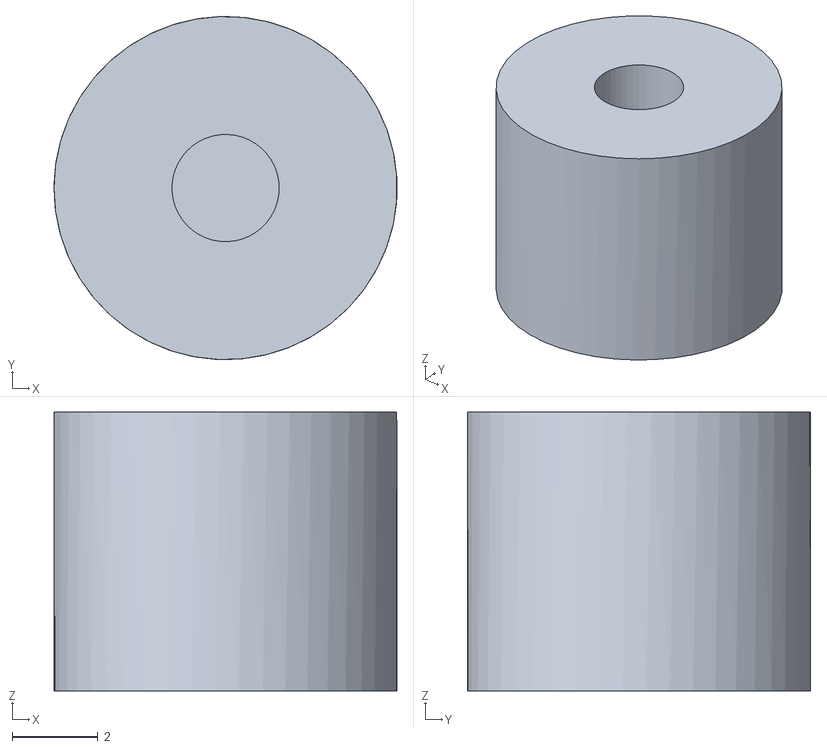
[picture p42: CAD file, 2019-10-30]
Amiga_Mean_Well_RT-50B_PSU_Mount_V2_standoff.stl
8.00 x 8.00 x 6.50

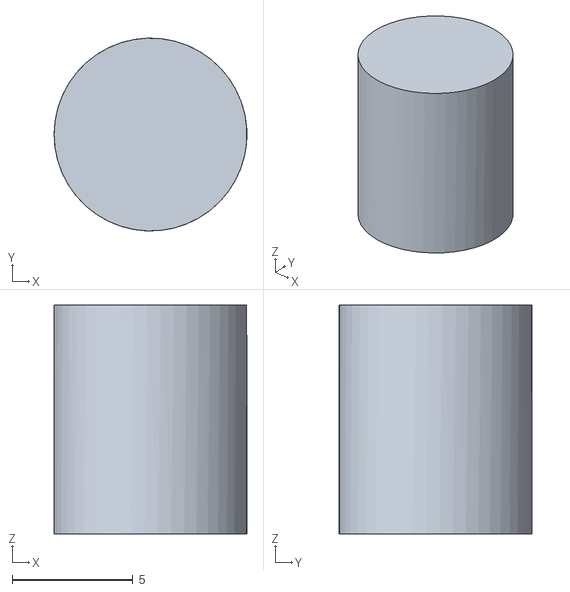
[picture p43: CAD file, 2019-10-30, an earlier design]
Amiga_Mean_Well_RT-50B_PSU_Mount_V1_standoff.stl
8.00 x 8.00 x 9.50

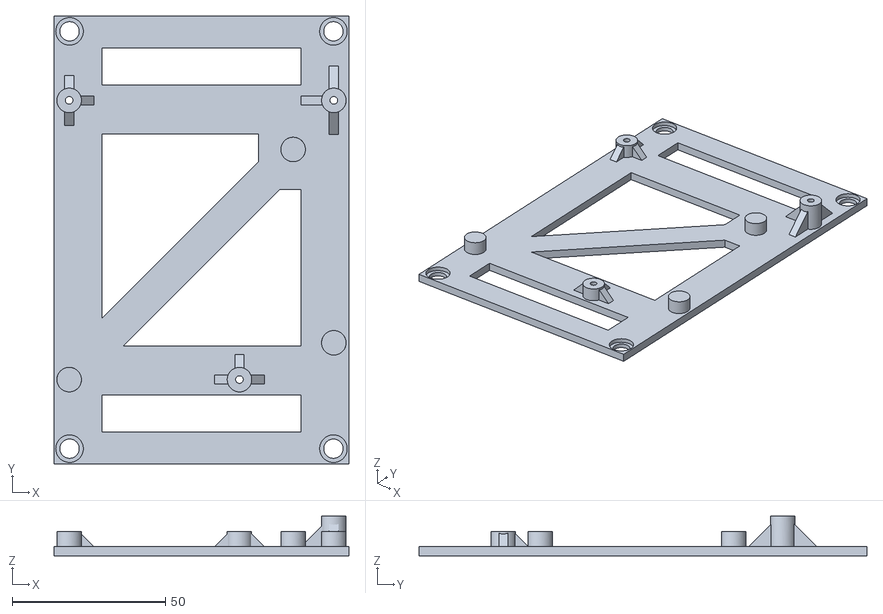
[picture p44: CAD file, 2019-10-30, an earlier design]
Amiga_Mean_Well_RT-50B_PSU_Mount_V1.stl
96.0 x 146.0 x 13.0

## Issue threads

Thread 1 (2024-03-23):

Dummy Load on RT-65B

danko79, 2024-03-23:
Hi, i need info, have for spare a Mean Well RT-65B, the power resistors is the same to RT-50B?
100 Ohm, 3 watt capable resistor is perfect for the -12V
47 Ohm, 5 watt capable resistor is suitable for the 12V
Thanks

jbilander, 2024-03-24:
Hi, I don't think a dummy load is needed on newer Mean Well PSU:s. Check your datasheet about minimum draw requirements. On this datasheet...

https://www.meanwell-web.com/content/files/pdfs/productPdfs/MW/Rt-65/RT-65-spec.pdf

...it says: 0 ~ 8A, 0 ~ 3.5A, 0 ~ 1A for the three outputs, so it seems there can be zero load on +12V and -12V and it will still regulate properly.

Also notice that the 65B has different dimensions than the 50B that the mounting bracket is designed for.

https://www.meanwell-web.com/content/files/pdfs/productPdfs/MW/Rt-50/RT-50-spec.pdf

danko79, 2024-03-24:
Hi ok, many thanks.

Closed 2024-03-24.
